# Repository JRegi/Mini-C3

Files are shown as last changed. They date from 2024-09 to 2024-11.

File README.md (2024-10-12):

# MiniC3 - PCB

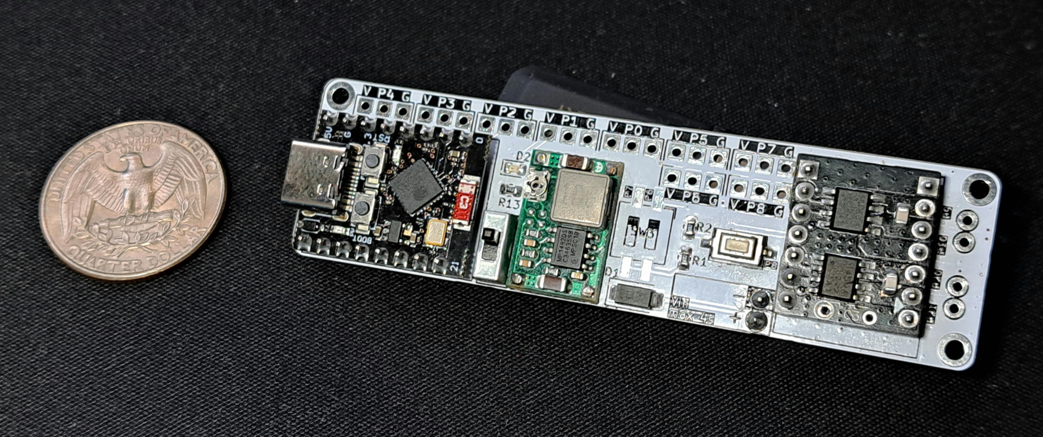
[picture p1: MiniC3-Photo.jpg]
MiniC3-photo


## Description:
MiniC3 is a PCB meant for amateur MiniSumo, featuring:
  -  ESP32-C3 Super Mini 
  -  MP2703 (Mini 360) Step-down module
  -  [Dual TB67H450FNG Driver module](https://github.com/JRegi/Driver-Module-TB67) (or [TA6586 Module](https://github.com/JRegi/Driver-Module-TA6586))

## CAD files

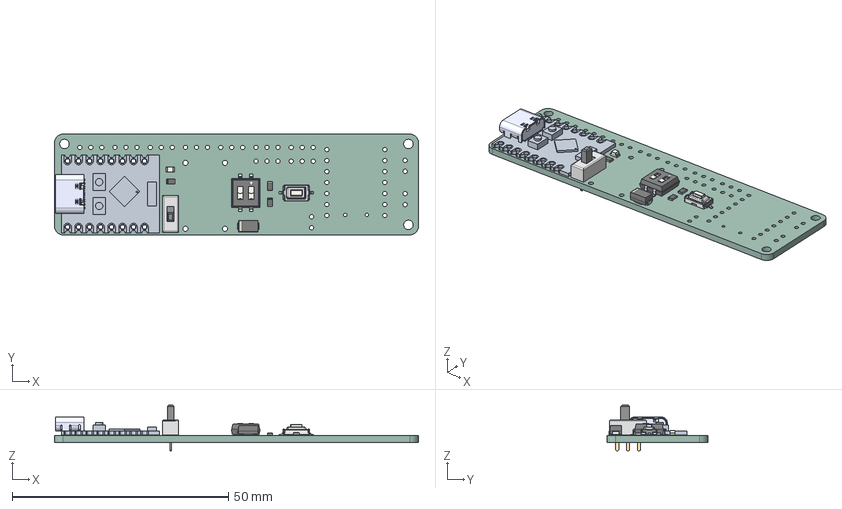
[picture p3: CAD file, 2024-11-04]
3D_Mini-C3.step
84.1 x 23.3 x 10.6 mm
PTS636Sx25SMTRLFS
D_SMA
R_0805_2012Metric x 3
LED_0805_2012Metric
ESP32-C3 SuperMini
SW_DIP_SPSTx02_Slide_67x664mm_W861mm_P254mm_LowProfile
Interruptor
Mini-C3_PCB

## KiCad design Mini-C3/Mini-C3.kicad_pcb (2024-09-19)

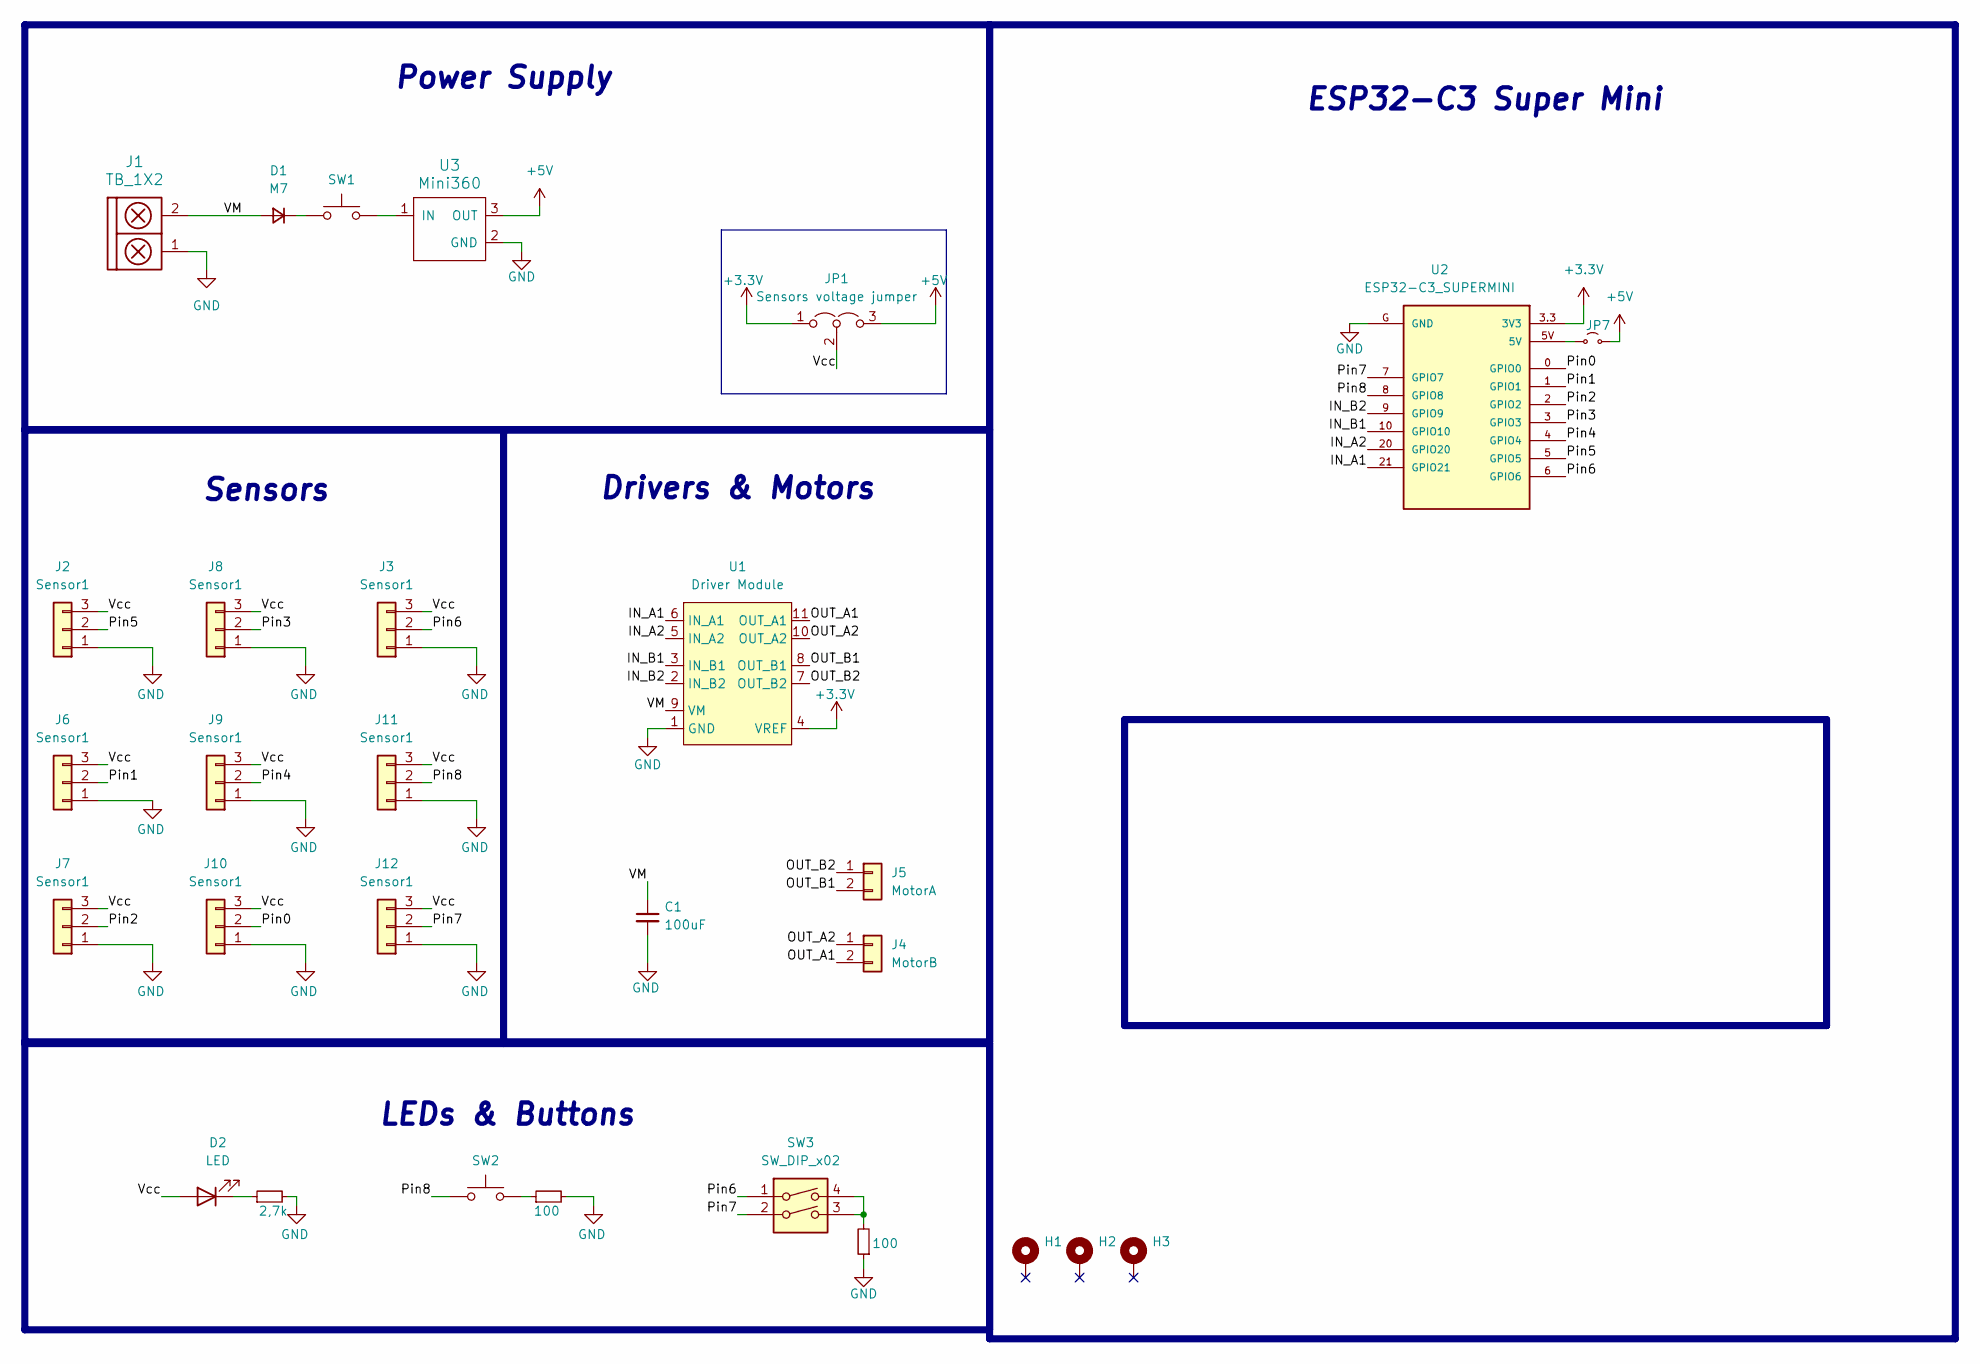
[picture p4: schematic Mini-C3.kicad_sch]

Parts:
C1: 100uF; C_Disc_D4.3mm_W1.9mm_P5.00mm
D1: M7; D_SMA
D2: LED; LED_0805_2012Metric
H1, H2, H3: MountingHole_Pad; MountingHole_2.2mm_M2_DIN965_Pad
J1: TB_1X2; MyPinHeader-01x02-vertical
J2, J3, J6, J7, J8, J9, J10, J11, J12: Sensor1; PinHeader_1x03_P2.54-THT
J4: MotorB; MyPinHeader-01x02
J5: MotorA; MyPinHeader-01x02
JP1: Sensors voltage jumper; SolderJumper-3_P2.0mm_Open_TrianglePad1.0x1.5mm
JP7: Jumper_2_Small_Open; SolderJumper-2_P1.3mm_Open_RoundedPad1.0x1.5mm
R1, R2: 100; R_0805_2012Metric
R13: 2,7k; R_0805_2012Metric
SW1: SW_Push; SW_Slide-03_P2.54_L9_W4_H7
SW2: SW_Push; SW_Tactile_SPST_NO_Straight_CK_PTS636Sx25SMTRLFS
SW3: SW_DIP_x02; SW_DIP_SPSTx02_Slide_6.7x6.64mm_W8.61mm_P2.54mm_LowProfile
U1: Driver Module; Dual-Driver-Module
U2: ESP32-C3_SUPERMINI; MODULE_ESP32-C3_SUPERMINI
U3: Mini360; Mini360_step-down

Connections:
+3.3V: JP1.1 (A), U1.4 (VREF), U2.3.3 (3V3)
+5V: JP1.3 (B), JP7.2 (B), U3.3 (OUT)
/IN_A1: U1.6 (IN_A1), U2.21 (GPIO21)
/IN_A2: U1.5 (IN_A2), U2.20 (GPIO20)
/IN_B1: U1.3 (IN_B1), U2.10 (GPIO10)
/IN_B2: U1.2 (IN_B2), U2.9 (GPIO9)
/OUT_A1: J4.2, U1.11 (OUT_A1)
/OUT_A2: J4.1, U1.10 (OUT_A2)
/OUT_B1: J5.2, U1.8 (OUT_B1)
/OUT_B2: J5.1, U1.7 (OUT_B2)
/Pin0: J10.2, U2.0 (GPIO0)
/Pin1: J6.2, U2.1 (GPIO1)
/Pin2: J7.2, U2.2 (GPIO2)
/Pin3: J8.2, U2.3 (GPIO3)
/Pin4: J9.2, U2.4 (GPIO4)
/Pin5: J2.2, U2.5 (GPIO5)
/Pin6: J3.2, SW3.1, U2.6 (GPIO6)
/Pin7: J12.2, SW3.2, U2.7 (GPIO7)
/Pin8: J11.2, SW2.1, U2.8 (GPIO8)
/VM: C1.1, D1.2 (A), J1.2, U1.9 (VM)
/Vcc: D2.2 (A), J2.3, J3.3, J6.3, J7.3, J8.3, J9.3, J10.3, J11.3, J12.3, JP1.2 (C)
GND: C1.2, J1.1, J2.1, J3.1, J6.1, J7.1, J8.1, J9.1, J10.1, J11.1, J12.1, R1.2, R2.1, R13.2, U1.1 (GND), U2.G (GND), U3.2 (GND)
unnamed: D1.1 (K), SW1.2
unnamed: D2.1 (K), R13.1
unnamed: JP7.1 (A), U2.5V
unnamed: R1.1, SW2.2
unnamed: R2.2, SW3.3, SW3.4
unnamed: SW1.1, U3.1 (IN)

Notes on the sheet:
Sensors
Power Supply
LEDs & Buttons
ESP32-C3 Super Mini
Drivers & Motors

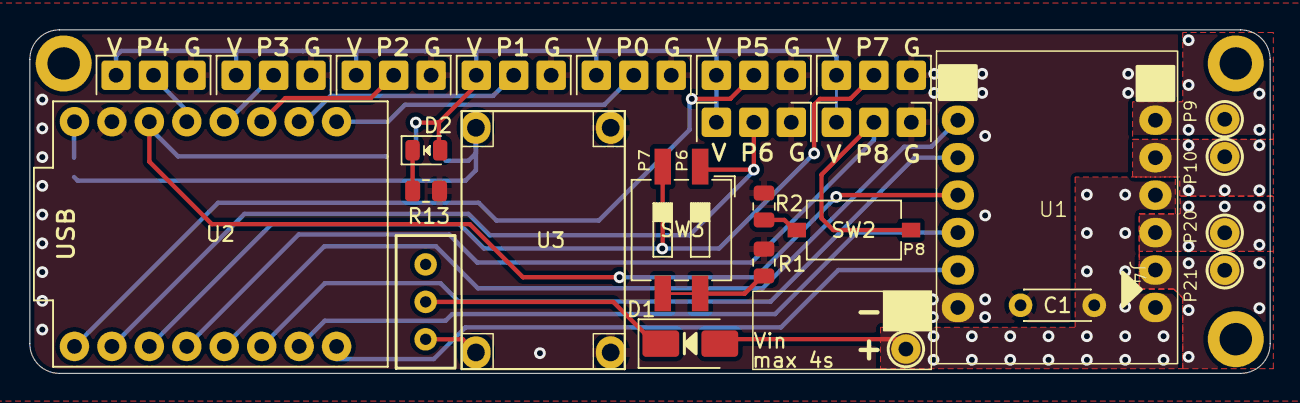
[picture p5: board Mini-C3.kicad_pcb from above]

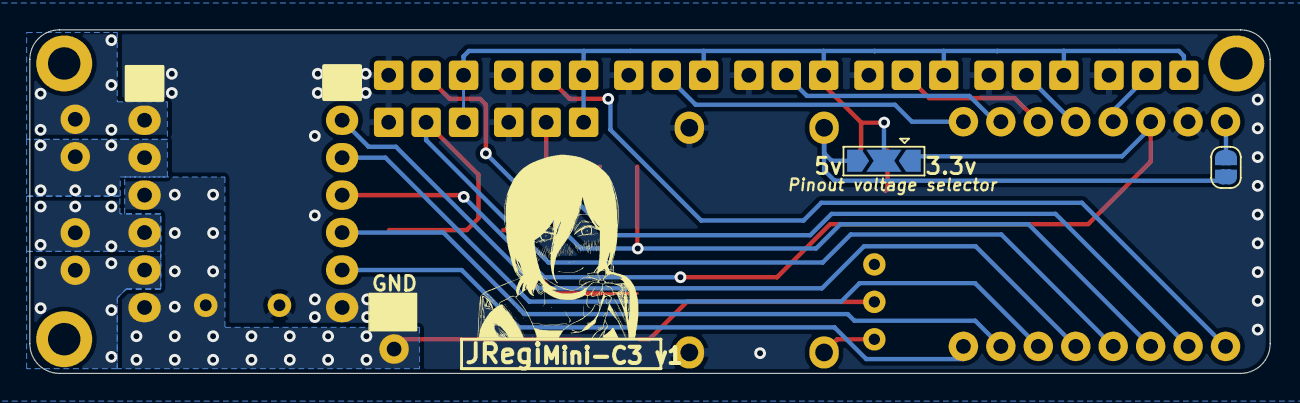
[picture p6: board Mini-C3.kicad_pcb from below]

Board: 2 copper layers, 84.1 x 23.3 mm, 29 parts (2 on the bottom side), 28 nets.

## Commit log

2024-09-09 KiCad project
    Added the KiCad project and updated the schematic.
    [Mini-C3.kicad_pcb, Mini-C3.kicad_sch]
2024-09-09 schematic & pcb
    ESP32-C3 pinout img added. The schematic is almost done.
    [Mini-C3.kicad_pcb, Mini-C3.kicad_sch]
2024-09-12 PCB components placement
    Improved the placement of the components.
    [Mini-C3.kicad_pcb, Mini-C3.kicad_sch]
2024-09-12 pecebé
    [Mini-C3.kicad_pcb, Mini-C3.kicad_sch]
2024-09-12 la pecebé
    [Mini-C3.kicad_pcb, Mini-C3.kicad_sch]
2024-09-13 PCB almost there
    [Mini-C3.kicad_pcb, Mini-C3.kicad_sch]
2024-09-15 Repositioned & added footprints
    Honestly there's so much that was done that I just can't put it all here, also maybe because I don't remember. You should see the changes for yourself. Who reads these anyway?
    [Mini-C3.kicad_pcb, Mini-C3.kicad_sch]
2024-09-15 Pin names
    [Mini-C3.kicad_pcb]
2024-09-16 panels again
    [Mini-C3-B_Cu.gbr, Mini-C3-B_Mask.gbr, Mini-C3-B_Paste.gbr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]
2024-09-17 silkscreen and gerber files again
    [Mini-C3-B_Cu.gbr, Mini-C3-B_Mask.gbr, Mini-C3-B_Paste.gbr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]
2024-09-19 yet another gerber files update
    [Mini-C3-B_Cu.gbr, Mini-C3-B_Mask.gbr, Mini-C3-B_Paste.gbr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]
2024-09-19 regenerated gerber files
    [Mini-C3-B_Cu.gbr, Mini-C3-B_Mask.gbr, Mini-C3-B_Paste.gbr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]
2024-10-11 Schematic change
    [Mini-C3.kicad_sch]
2024-11-04 3D Files
    [3D_Mini-C3.step]
